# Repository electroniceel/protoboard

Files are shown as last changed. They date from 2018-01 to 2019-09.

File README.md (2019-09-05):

Advanced protoboard layout with 1.27mm pitch for smd parts
==========================================================

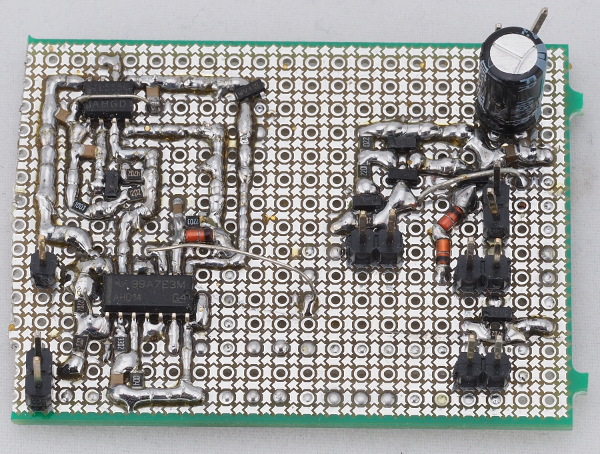
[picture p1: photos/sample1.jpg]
Sample 1
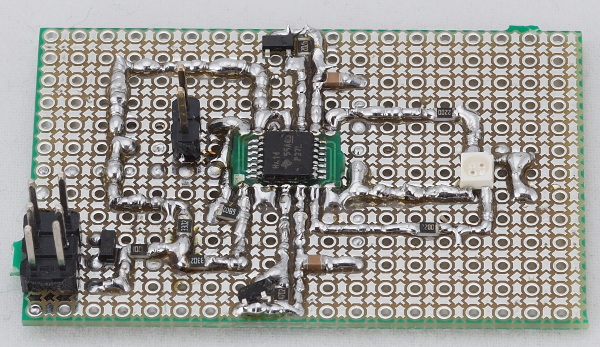
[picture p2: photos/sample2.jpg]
Sample 2
|  |  |

Main Features
-------------

* Plated through holes in standard 2.54mm raster like on traditional protoboard
* Pads for smd parts in 1.27mm raster in between
* SOIC parts can directly be used without adapters
* SMD pads are not contacted to the other side:
  * Different tracks can either cross each other or connect
  * No wires to solder in like on non-plated-through protoboard
* Allows for much more dense layout

Supported Packages
------------------

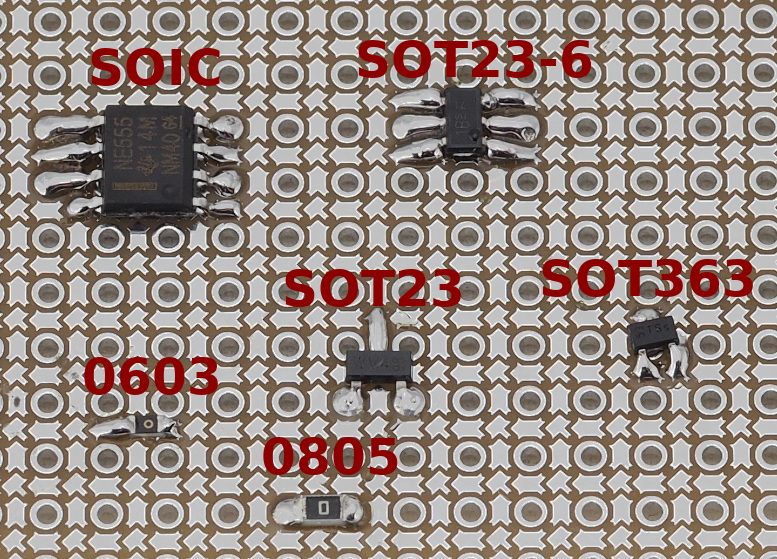
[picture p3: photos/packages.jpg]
Supported Packages


These packages can be directly used without adapter:

* DIP (Through hole, 2.54mm pitch)
* SOIC (SMD, 1.27mm pitch)
* SOT-23-3 (SMD)
* SOT-23-6 (SMD)
* SOT-323 (SMD)
* SOT-89 (SMD)
* SOT-223 (SMD)
* TO-252/DPAK (SMD)
* All 2 pin packages like for resistor and diodes known to me

Adapters to 1.27mm pitch smd are provided for these packages:

* TSSOP-14
* TSSOP-16
* SOT-363/SC-70

Bottom variants (Ground plane option)
-----------

My original design uses the 1.27mm pattern on both sides. For some analog and RF circuits I wanted a better GND plane.
So I made a variant with a near-solid GND plane on the bottom side.

* Near solid copper plane on the bottom side
* Plated-through holes in 2.54mm raster
    * The holes have a minimal annular ring of 0.15mm
    * Around the ring is another 0.15mm space
    * After that the GND plane begins
* A hole just soldered on the top is not automatically connected to the GND plane because of the 0.15mm space
* Just put a blob of solder on the bottom to connect a hole to the GND plane

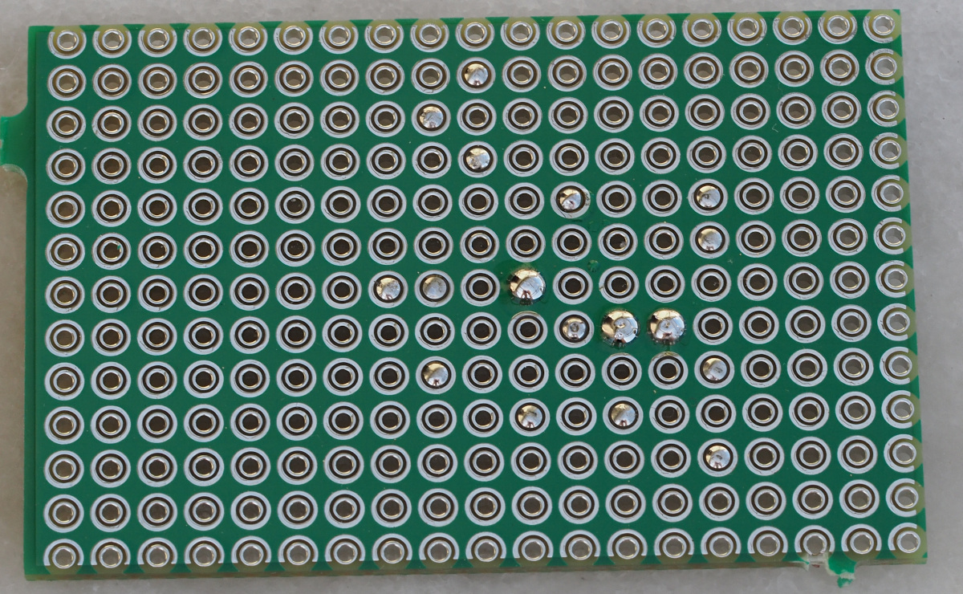
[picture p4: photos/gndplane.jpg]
GND plane
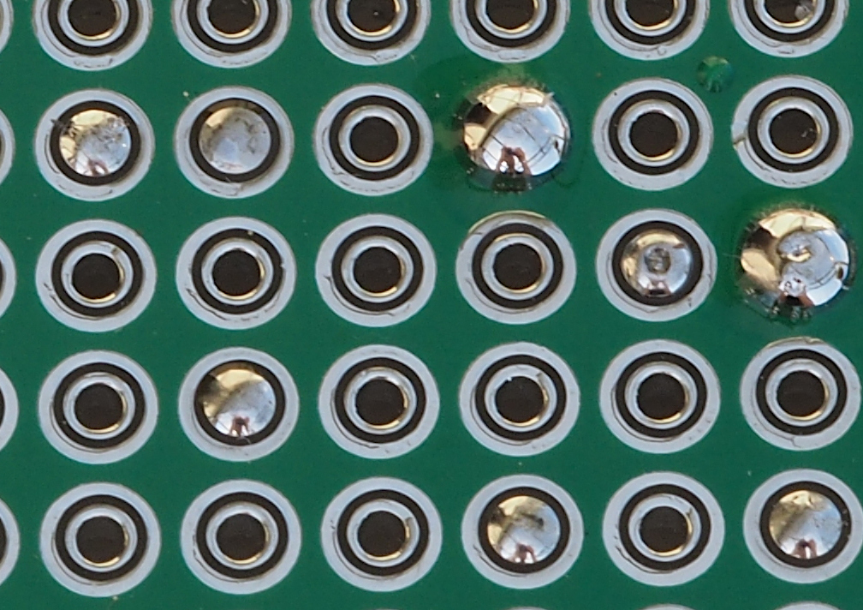
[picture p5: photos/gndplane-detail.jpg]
GND plane detail
|  |  |

How to get?
-----------

Chinese pcb manufacturing services became so cheap even for small quantities
that it's easiest for you to order the protoboards there for yourself.

When I began designing these boards, I ordered samples from Elecrow and JLCPCB and both came out fine. But
when ordering some new boards, JLCPCB now declined to manufacture them with (cheap) HASL surface finish and only
wanted to manufacture them if I switched to (more expensive) ENIG. They explained that the HASL process might leave small
solder blobs on the surface creating shorts. Elecrow continued to manufacture them without any issues.

So I recommend to order the boards from [Elecrow](http://www.elecrow.com/referral-program/MjA0ODlqMnQ=/).

Finished gerber zips ready for ordering can be found in the ["gerber" directory](https://github.com/electroniceel/protoboard/tree/master/gerber).

If you prefer another layout, see below.

Production options
----------------

* Color doesn't matter as there is next to no soldermask on the boards
* I found 1.2mm thickness a good compromise between rigidity and ease of cutting
* But I'd go down to 1mm thickness if you prefer one big board without slots and want to cut it for each project to fit

Making your own layout
----------------------

* All neccessary KiCAD source files are provided in the ["kicad" directory](https://github.com/electroniceel/protoboard/tree/master/kicad)
* Open the layout in pcbnew
* Set the grid to 1.27mm
* Take the base pattern and copy it as much as you like
* Draw the pcb edges (and maybe routed slots) around

For the variant with GND plane on the bottom:

* Use the "-oneside" footprints on the top side
* Use "tht-0.8-thin-bottom" on the bottom side

Soldering tips
--------------

Populating this protoboard needs obviously a bit more care than regular protoboard. Here are
some tips to get you started.

Use a smaller soldering tip than usual, I prefer a 1.2mm chisel type (JBC C245-906).

Reduce the soldering temperature to drag traces. I prefer 295°C for Sn60Pb40 solder
with my JBC station, other stations may need it slightly hotter.

The lower temperature makes the solder flow less liquid and so it is a bit easier to control where
it should flow and where not. So you can drag the solder blobs around a bit. If the solder doesn't
want to make the connection you need, take the tip away and let the spot cool for about 5 seconds. Then
try again.

This needs a bit of getting used to as it is completely different than populating boards with pads etched
to match the circuit where you usually want heat transfer as fast and even as possible.

Similar projects
----------------

This layout might not fit everyones needs. Here are some other protoboard designs with a grid of 1.27mm or lower:

* [Black Mesa Labs BML 50MIL](https://blackmesalabs.wordpress.com/2017/12/03/bml-50mil-0-050-proto-boards-for-rapid-surface-mount-prototyping/), free to download sources & gerbers
* [Busboard 50x50mil SMTpads](https://www.busboard.com/surfacemountpcbs), commercial
* [FYD Open Source Hardware](https://www.aliexpress.com/item/32774106087.html), commercial

License
-------


This work is licensed under a [Creative Commons Attribution 4.0 International License](https://creativecommons.org/licenses/by/4.0/).

Please link to http://git.io/vNUDX for attribution.

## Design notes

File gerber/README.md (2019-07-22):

Advanced protoboard - Finished gerber ZIPs
==========================================

You can directly send these ZIPs to prototype pcb manufacturers
for production. They are all in the common 10x10cm size.

protoboard-5x3.zip
------------------

* 6 small protoboards per pcb, separated by milled slots
* Roughly sized 5x3cm each

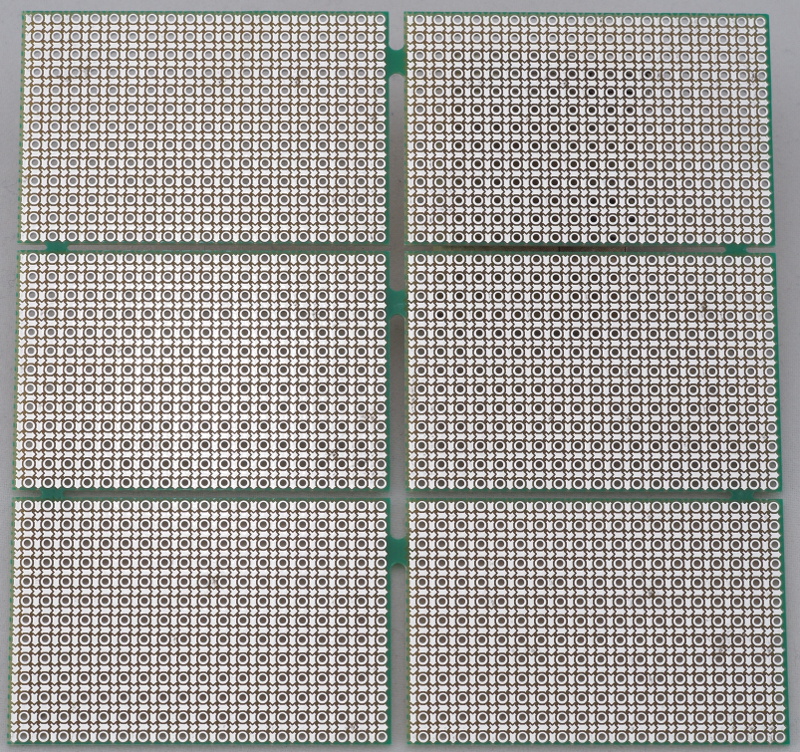
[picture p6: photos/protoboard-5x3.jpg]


protoboard-6x4-breakout.zip
---------------------------

* 3 small protoboards per pcb, separated by milled slots
* Roughly sized 6x4cm each
* 17 adapters for SC-70
* 4 adapters for TSSOP-14
* 4 adapters for TSSOP-16

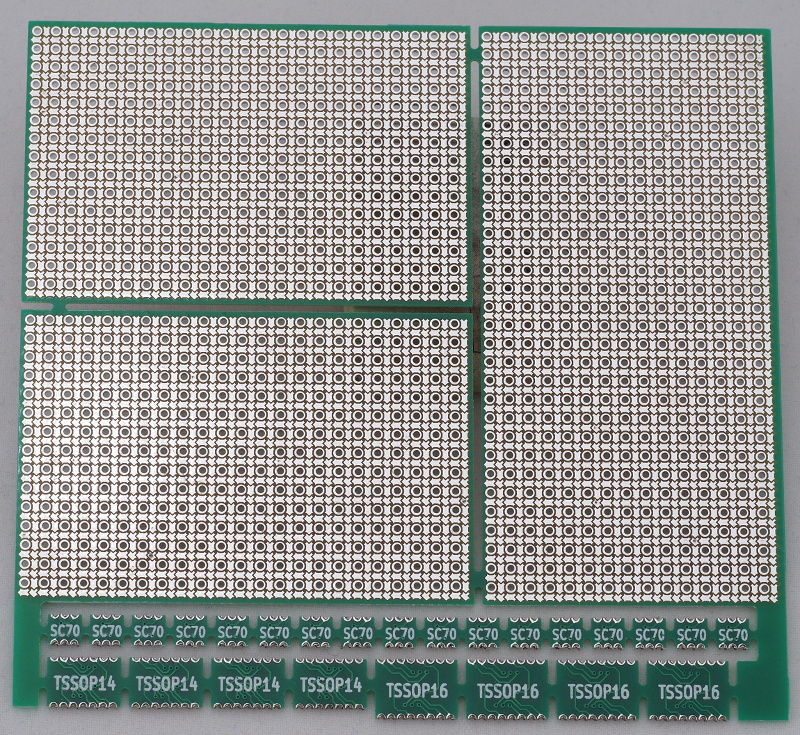
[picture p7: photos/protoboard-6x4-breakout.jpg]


protoboard-10x5.zip
-------------------

* 2 protoboards per pcb, separated by milled slots
* Roughly sized 10x5cm each

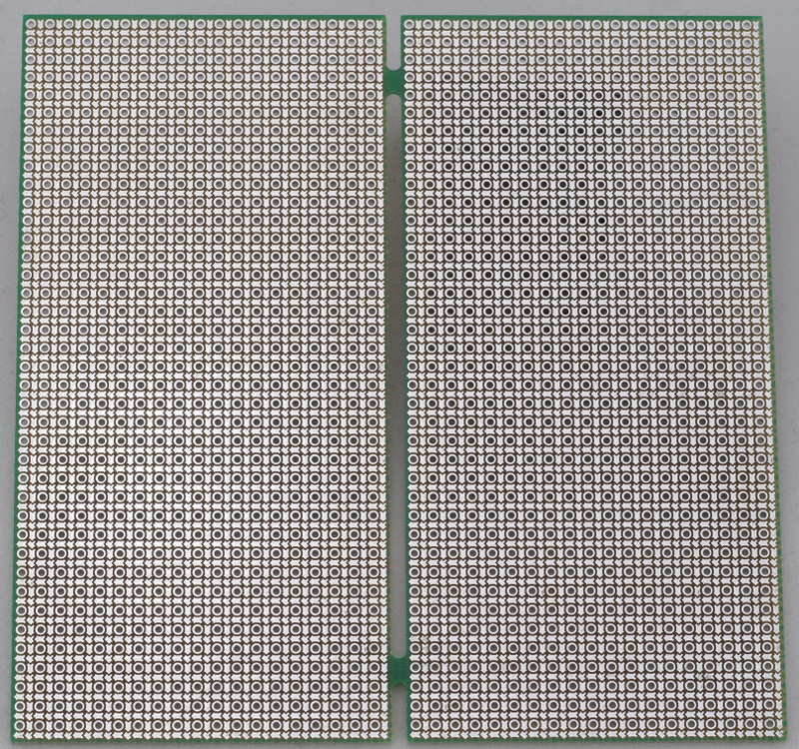
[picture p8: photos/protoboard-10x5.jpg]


protoboard-10x10.zip
-------------------

* one large protoboard in 10x10cm, no slots
* No photo as I haven't received pcbs of this design yet

protoboard-10x5-gndplane.zip
-------------------

* 2 protoboards per pcb, separated by milled slots
* Roughly sized 10x5cm each
* variant with gnd plane (see https://github.com/electroniceel/protoboard#bottom-variants-ground-plane-option)

protoboard-5x3-gndplane.zip
------------------

* 6 small protoboards per pcb, separated by milled slots
* Roughly sized 5x3cm each
* variant with gnd plane (see https://github.com/electroniceel/protoboard#bottom-variants-ground-plane-option)

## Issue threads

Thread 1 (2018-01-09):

Board outline files missing or empty

imjosh, 2018-01-09:
Attempted to get a quote from https://jlcpcb.com by uploading the zipped gerbers, but the process seemed to fail with no board preview shown.  I tried using OSHPark which produced some error messages:

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

I tried w/ the 5x3 and 10x5 protoboards with the same basic result.

electroniceel, 2018-01-09:
Strange, I used exactly these files for ordering. Can it be that the files got corrupted during download?

Please try downloading the whole repository using git clone instead of just a download with your browser. A git client always does a full checksum verification during download.

Then use a online gerber viewer like https://gerber-viewer.easyeda.com/ to verify them. I see the proper layout when using this viewer, just the milled slots inside of the pcb are not rendered correctly. They still come out fine when ordering at JLCPCB/Easyeda of course, inside slots are just something a lot of the free gerber tools don't seem to get right.

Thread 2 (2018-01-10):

JLCPCB order denied

Addy771, 2018-01-10:
Hello and thanks for the excellent protoboard designs. I tried to order the "protoboard-6x4-breakout" from JLCPCB, but the order was denied:
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

Were you able to order this through JLCPCB before?

electroniceel, 2018-01-10:
I just checked and I did order this file just at Elecrow, while I ordered the other designs at JLCPCB.

From their message It seems like they can't make the small SC-70 breakouts. Elecrow was able to make them, but sometimes there were parts of the through hole plating hanging next to the hole. No big issue, a bit of sandpaper fixes it.

Maybe JLCPCB has a special technique to make them with better quality, but that probably won't work with the small pcbs.

You can now either remove the SC-70 breakouts (in Kicad or a gerber editor) or order this design at another fab like Elecrow. I'll add a note to the readme.

Addy771, 2018-01-10:
Thanks for the information. I'll just order the 5x3's instead. The breakouts aren't very necessary for me, but I do want to place the order at JLCPCB so I can get an idea of what their turnaround time really is.

Addy771, 2018-01-11:
I am changing my order to the 5x3's, and JLCPCB has informed me that they won't do half-cut holes at all, so the other breakout boards won't work either.

mpmarks, 2018-01-31:
I got the 5x3 and 6x4 proto boards fabricated by DirtyPCBs.com. No problems at all. I just uploaded the gerbers and they fabricated them without any issues. 10 5x3 boards and 10 6x4 boards cost ~$50 with shipping. They took about 3 weeks to arrive.

Thanks for the design work! I think the boards will be quite useful for several projects.

Addy771, 2018-01-31:
Yeah, JLCPCB also made the 5x3 boards for me and they look great. I've already used one, but it took some experimenting to get it to work. Using 63/37 rosin core solder, I found that I had to turn the temperature way down to be able to make tracks with the solder. When the temperature is too high, the solder is nearly impossible to bridge between pads.

andrewcchen, 2018-08-13:
My order for 5x3's at JLCPCB got denied

> Hi， there is only holes in the board and you select surface finish with HASL. The tin will connect together to cause the short circuit.Please select ENIG if you need to do the board,thanks~

Seeing the pictures here I don't think HASL is really a problem. Maybe they just didn't want to drill so many holes for $2.

luftek, 2018-08-14:
What is your Pads to Mask Clearance? Was it set to 0.0mm?
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

andrewcchen, 2018-08-14:
I used the gerber files `protoboard-5x3.zip` from the repo, which I assume has been used successfully before?

luftek, 2018-08-14:
@andrewcchen Yes, originally there is no solder mask between pads. I added it, to look like
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
Will report if they accept/deny.

luftek, 2018-08-15:
Their online viewer couldn't display gerbers. Had to wait. Design was approved.

vatrat, 2018-10-05:
JLCPCB here.

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

I'm not entirely certain, but it looks like the layers are messed up in the picture. I used the 5x3 gerber zip without modifications.

electroniceel, 2019-07-21:
I do not recommend to order these boards at JLCPCB anymore.
See https://github.com/electroniceel/protoboard#how-to-get

mytja, 2020-11-09:
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
Hmmm.
They approved it to me!

electroniceel, 2020-11-09:
Thank you for the feedback.

I have made the experience that either the exact criteria for acceptance change from time to time, or, and I think that is more probable, it depends on which engineer was randomly assigned to checking your design. One is more relaxed and the other one more strict. So if not accepted, do a very small change (I think they do checksum matching of existing designs) and try again a few days later...

Closed 2019-07-21.

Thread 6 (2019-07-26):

ESP32?

sixtyfive, 2019-07-26:
Thinking of ordering a bunch of protoboards to keep around because they seem to be generally useful, but also I have one concrete use, which would include an esp-wroom-32 (2mm raster!). Has anyone ever used a similar package on that protoboard layout?

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

(Source: https://www.espressif.com/sites/default/files/documentation/esp32-wroom-32_datasheet_en.pdf)

One thing people do is this, which would obviously work. Just wondering if there is any concrete example for this layout, especially one that would use less vertical space than the below method.

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

(Source: https://www.esp8266.com/viewtopic.php?f=13&t=782)

electroniceel, 2019-07-26:
The 2mm raster won't work well with my protoboard design. You'd have to lift the esp32-board to prevent shorts and use wires like in your picture.

Also you have to keep the space below the pcb antenna free, even unpopulated protoboard-pads will affect the antenna.

So maybe a dip adapter exactly as shown in your photo is the best solution. Plugging the 2.54mm raster pin headers into the protoboard is no problem.

sixtyfive, 2019-07-26:
All good considerations, thank you! Regarding the antenna thing, I completely hadn't thought about that. Perhaps best to scrape off the protoboard-pads below that. It's for a prototype anyways, so perhaps we'll just make the enclosure a little larger.

Closed 2019-07-26.

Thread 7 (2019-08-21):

FR: More IC package adapters

sixtyfive, 2019-08-21:
Hi! So my package from China has arrived and I've been playing with the boards a little. Somehow I managed to solder a couple of things onto them with an old, huge ERSA MultiTip C15 without making any unwanted connections. Nice. The IC adapters are a little finnicky but can also be made to work with a bit of practice.

One thing that makes me a little sad though: no SSOP (up to 28 pins, i.e. FTDI232), nor QFP (also up to 28 pins, i.e. CP2102 or even up to 64 pins, i.e. ADS1296), nor SON (i.e. the 10-pin TPS63031 or the wide 12-pin
LM27762 which are both pretty cool), nor BGA (another nice TI chip as an example, the 12-pin LM3686).

I realize there's a myriad of packages out there and each takes a lot of work, but perhaps at some point there'll be enough interest that an adapter-only board variant might be warranted... :)

electroniceel, 2019-08-22:
For more complex stuff like microcontrollers or FTDI232 I prefer small breakout boards which already have the important footprints, like capacitors, crystals,... on them. But if you are using a part the first time and want to test it out, a footprint-only adapter might make sense.

Feel free to create some footprints and send pull requests.

sixtyfive, 2019-08-22:
That works fine unless you're pressured for space. For now I'm going with the isolation-tape-power-glue-enameled-wire technique. If at some point I get around to learning KiCad I'll gladly give it a shot.

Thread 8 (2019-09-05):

Derrivative work

renzenicolai, 2019-09-05:
Hello Electroniceel!

Thank you for making such a great prototyping board :-)

I've got a question about using your protoboard design in a small run of boards for an event we're organising. We plan on handing them out as nametags/badges with a prototyping area.

How would you like to be credited? Is a mention on the page on our website about the board okay with you or would you like to be mentioned in the silkscreen of the board itself?

Greetings,
Renze Nicolai
(https://github.com/badgeteam / https://badge.team)

electroniceel, 2019-09-05:
> I've got a question about using your protoboard design in a small run of boards for an event we're organising. We plan on handing them out as nametags/badges with a prototyping area.

Nice idea

> How would you like to be credited? Is a mention on the page on our website about the board okay with you or would you like to be mentioned in the silkscreen of the board itself?

I'd appreciate it if you link to this github repo, so that anyone interested can easily find it, make their own variant or send pull requests. You can either use the full url or the shortener http://git.io/vNUDX.

It would be ok if you do that on your website about the board. If you got plenty of free space on the back or something like that, you could also put it on the silkscreen. But I won't be angry if it doesn't fit and you just have it on the website.

Have fun with your event!

Closed 2019-09-05.

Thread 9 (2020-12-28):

Fix description for 6x4 boards

gene-pavlovsky, 2020-12-28:
Hi

The description for 6x4 boards (gerber/README.md) says: "Roughly sized 6x4cm each"
In fact there are two ~6x4cm boards and one ~8x4cm board per each 10x10 PCB.

Thanks for the project, the boards from Elecrow just came and they look great and super useful. Elecrow told me I have to pay extra 15 USD for the castellated holes (the adapters).

Take care!

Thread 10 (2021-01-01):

Add hole diameter to README

gene-pavlovsky, 2021-01-01:
Hello,

After receiving the boards from Elecrow, I've noticed that the holes are smaller in diameter than the regular 2.54 mm pitch perfboard/protoboard. Most of the components I use do fit, an exception are 5.08 mm pitch terminal blocks - those do fit on a normal protoboard I have.

If I managed to figure it out correctly (installed KiCad for the first time), it seems that your lovely boards have holes drilled 0.8 mm. Would be nice to mention this in the README.

Thanks
Gene

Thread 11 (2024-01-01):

Software for "place and route" / making layouts?

kittennbfive, 2024-01-01:
Hi,

thanks for your great project!

Is there a software (FLOSS, Linux) to help with layouts using these protoboards? Maybe there is a way to use Kicads PCBnew somehow? For standard protoboards (2,54mm) i sometimes just switch the grid to 2,54mm in this program and it works okay, but your boards are more "complex"...

A suitable tool would be a great addition to these files.

BTW and for information: I ordered 10 of the "big" (10x10cm) boards with thickness 0,8mm (iirc) and standard HASL from JLC and they processed the order just fine (somewhere in 2023).

Have a great new year!

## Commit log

2018-01-05 add gerber dir with zips ready for production
2018-01-05 add kicad source files
    [protoboard.kicad_pcb]
2018-01-05 add reference text to layout files
    [protoboard.kicad_pcb]
2018-01-05 add soldering tips
2018-01-06 resized images for gerber readme
2018-01-11 add protoboard-10x10 design without slots
2018-08-08 KICAD_V5: update library footprints with v5 pad option (using polygon for a pad)
2018-08-08 KICAD_V5: Use new version of footprints in template
    [protoboard.kicad_pcb]
2019-07-21 add kicad sources for variant with gnd plane
2019-07-21 add gerber files for variant with gnd plane
2019-07-21 add documentation for the gnd plane variants
2019-07-21 document how to create gndplane variant
2019-07-21 add link in gerber file documentation
